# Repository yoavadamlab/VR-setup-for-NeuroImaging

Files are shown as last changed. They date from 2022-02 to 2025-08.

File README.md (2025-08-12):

# Compact virtual realilty setup for neuroimaging

Using this stetup, we study neural activity in the mouse hippocampus during virtual navigation using voltage imaging & calcium imaging, and combining both with optogenetics.

Here we share the hardware &amp; software we developed for the behavioral setup.



## 3D printings
 
 We based our wheel design on [Arthur Sugden](https://github.com/asugden/bebox/tree/master/3d/wheel) model with slight changes.
 
 Our models can be found in [`3D models`](https://github.com/yoavadamlab/VR-setup-for-NeuroImaging/tree/main/3D%20models) directory which contains models for:
 
 - The wheel
 - U shape base for the wheel axis
 - Holders and axle
 - Screen for VR projection

Have a look [here](https://github.com/yoavadamlab/VR-setup-for-NeuroImaging/blob/main/3D%20models/Assembly.STL) on the assembled model.

## Electronics & more

- [Capacitance sensor](https://www.sparkfun.com/products/12041) - for lick detection.
- [Solenoid valve](https://theleedifference.com/products/#solenoid-valves/3) - for reward control.
- [H bridge](https://m.banggood.com/10-Pcs-Geekcreit-L298N-Dual-H-Bridge-Stepper-Motor-Driver-Board-p-1054211.html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) - for switching the 5V coming out of the Arduino with a 12V supply for the valve.
- [Rotary encoder](https://www.ia.omron.com/data_pdf/cat/e6b2-c_ds_e_6_1_csm491.pdf?id=487) - for recording the movement of the wheel.
- [Arduino Uno](https://docs.arduino.cc/hardware/uno-rev3) - controlling the electrical devices and recording inputs.
- [LED projector](https://www.optoma.com/ap/product/ml750st/#) - project the VR environment.
- [500 nm shortpass filter](https://www.edmundoptics.com/p/500nm-50mm-diameter-od-4-shortpass-filter/27788/) - prevent interference of light from the projector into the microscope objective. 
- [Bearings](https://www.4project.co.il/product/flanged-ball-bearing-5x14x5).

### Motorized control setup

We use this setup with mice freely running on the wheel, performing a behavioral task, or for motorized controlled locomotion experiment. Motorzied control uses the following: 

- [Motor](https://www.pololu.com/product/2207)
- [Motor controller](https://www.pololu.com/product/1376)

## Hardware all together

 We based the Wheel on [ThorLabs Breadboard](https://www.thorlabs.com/newgrouppage9.cfm?objectgroup_id=159) with ThorLabs standared posts and connectors.

### Mouse head fixation

 The mice head is fixed using [Neurotar head fixation system](https://www.neurotar.com/the-mobile-homecage/#stability).
 


### Reward delivery and lick detection

A plstic tube (filled with 10% sucrose water for reward delivery), was connected by thin rubber tubes, passing through a solenoid valve, and with the [Neurotar lick port](https://www.neurotar.com/the-mobile-homecage/#stability) at it's end. The solenoid valve was connected to an H-bridge for voltage supply. An electrical wire was soldered to the edge of a needle which compose on the lick port. This wire was connected to a capacitance sensor for mouse lick detection.



We used a motor for motorized control experiments or a rotary encoder for free running experiment:

### Motorized control

The motor was placed on the shaft and controlled by [Pololu control center](https://www.pololu.com/docs/0J44/3.1).



### Rotary encoder

 A rotary encoder was fixed on the shaft of the wheel to track the wheel rotation
  


### Arduino control

The H-bridge, capacitance sensor and the rotary encoder were connected to an Arduino Uno. The Arduino was connected to a standard computer, installed with the ViRMen environment. 



Have a look [here](https://www.circuito.io/app?components=9442,10456,11021,11696,44752,860025) for interactive circutry design.

### The projector

The projector was mounted on the ThorLabs breadboard to project the VR environment on 3D printed screen that was placed in front of the mouse.
 

 
## Software

The VR rendering was designed and executed by [ViRMEn v.2016-02-12](http://pni.princeton.edu/pni-software-tools/virmen-download).
Configurations files for 3 different VR worlds can be found at [`ViRmEn\Mice_Training.mat`](https://github.com/yoavadamlab/VR-setup-for-NeuroImaging/tree/main/ViRmEn).

This is as nexmaple of the virtual environment from the mouse perspective:



Besides the VR design we had to control the following:
- Progress of the virtual environment according to mouse rotation of the wheel
- Delivering specific amounts of reward (sucrose water) at a specified location
- Keep track of the mouse licking (to monitor additional behavior to demonstrate learning of the task)
- Save the behavioral data from the training and imaging sessions for future analysis

The [arduino code](https://github.com/yoavadamlab/VR-setup-for-NeuroImaging/blob/main/Arduino/wheel_control.ino) is used for hardware control. Data is sent to Virmen every 10 ms via serial port communication to indicate whether a lick occured and the amount of wheel rotation.
Virmen also sends data to the arduino via the same serial port, to indicate when to open the valve for reward delivery.
We also supply compiled arduino files for automatic initialization of the arduino board from the virmen script.

The software allows flexible training logic based on the mouse progress. In the beginning of each training session, the trainer needs to declare the current training stage:



Then, the mouse meta-data should be given:



Now, training begins and we can track the mouse preformance:



The virmen experiment and moveforward code can be found at [`ViRmEn`](https://github.com/yoavadamlab/VR-setup-for-NeuroImaging/tree/main/ViRmEn) directory.
After training finished the mouse training data was saved as a csv. file and an automated python script is running to preform analytics of the current training session. The script sends summary data to the lab members emails with the curnet day data, including plots regarding the training history of the mouse:



Have a look at the [daily summary plots](https://github.com/yoavadamlab/VR-setup/files/7994692/daily_plots.2.pdf).

The code for the behavioral analysis can be found in the [`Behavior Analysis`](https://github.com/yoavadamlab/VR-setup-for-NeuroImaging/blob/main/Behavior%20Analysis/Mice_training_data_analysis_wheel_setting.py) directory.

## Contact us

For more information and quetsions you are welcome to contact us by openning an issue.

## Contributors
Project was led by [Yaniv Melamed](https://elsc.huji.ac.il/lab-members/yaniv-melamed/) in collaboration with [Rotem Kipper](https://elsc.huji.ac.il/lab-members/rottem-kipper/) and advice from all [Adam Lab members](https://elsc.huji.ac.il/people-directory/faculty-members/yoav-adam/). 3D priniting was provided by [ELSC FabLab](https://elsc.huji.ac.il/research-and-facilities/expertise-centers/elsc-fablab/).

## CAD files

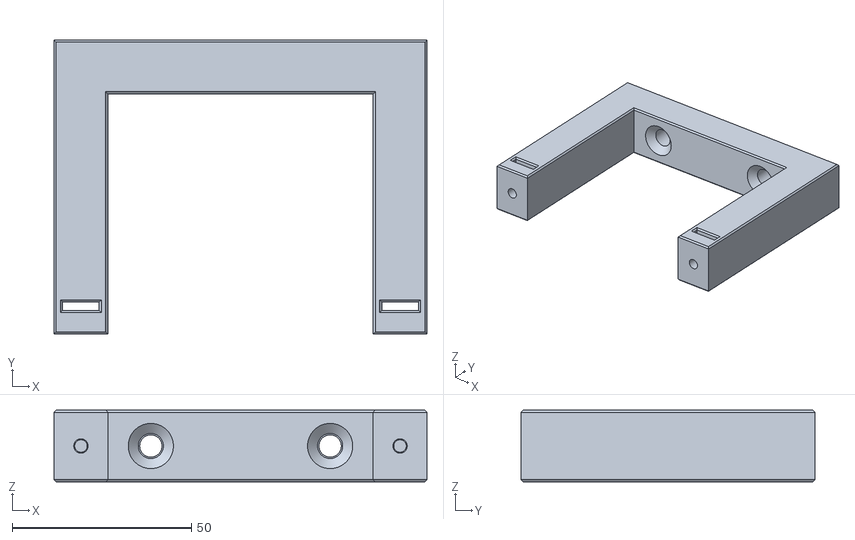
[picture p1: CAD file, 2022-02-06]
3D models/base and axle/Base V4.stl
104.0 x 82.0 x 20.0

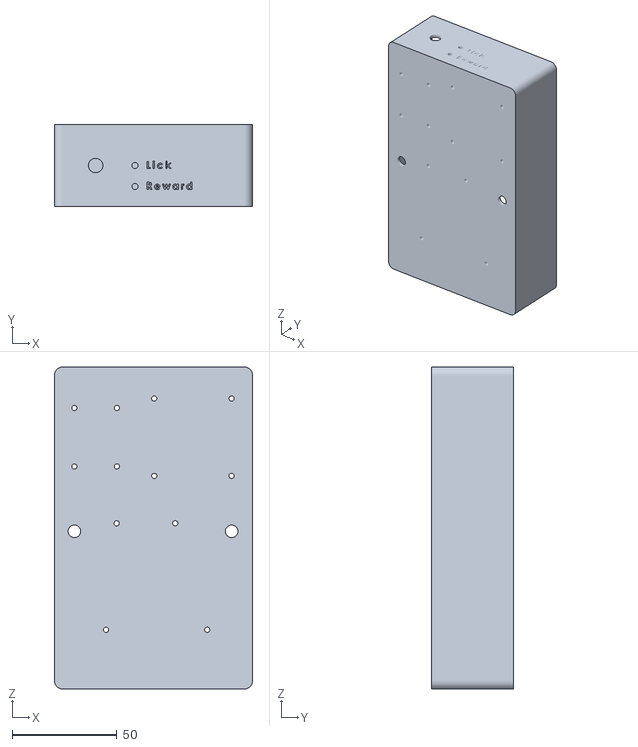
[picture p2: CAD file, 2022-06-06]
3D models/Circuit Box/Github just case.STL
94.6 x 39.0 x 153.6

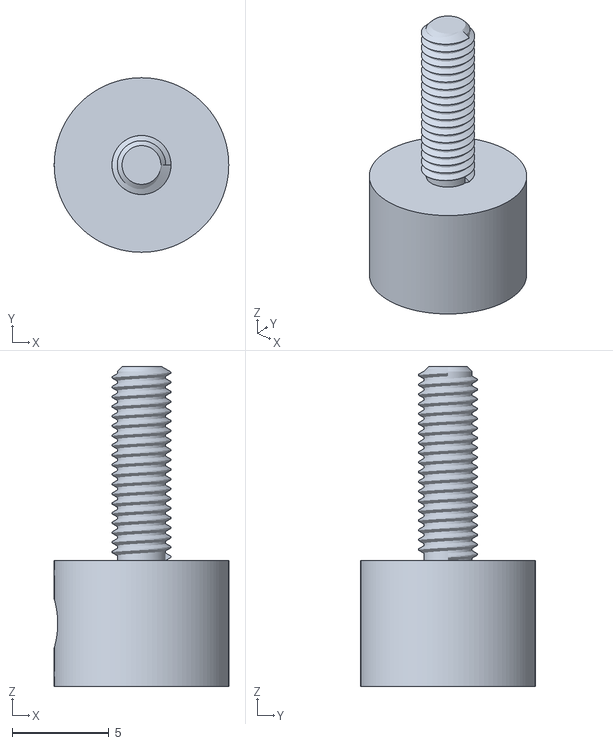
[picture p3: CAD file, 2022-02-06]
3D models/Motor parts/Motor insert V4.stl
9.00 x 9.00 x 16.5

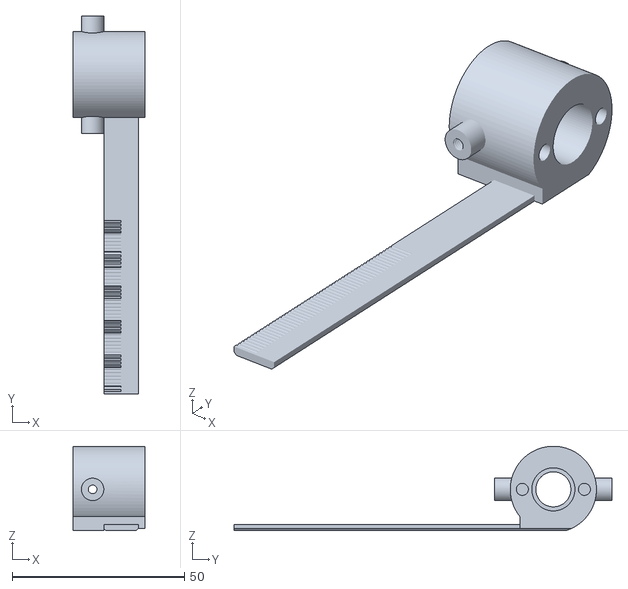
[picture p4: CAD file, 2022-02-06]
3D models/Rotary Encoder parts/Encoder holder V4.stl
21.0 x 109.6 x 24.5

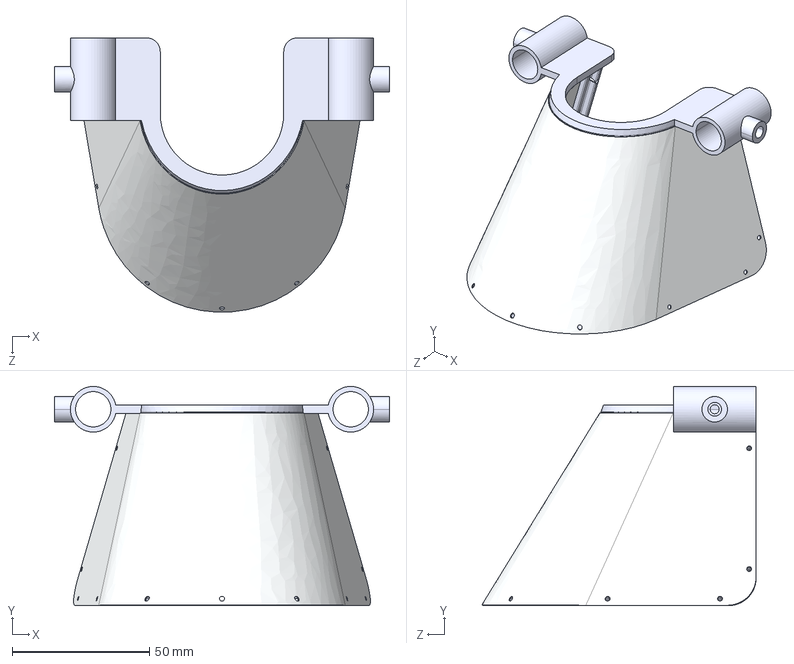
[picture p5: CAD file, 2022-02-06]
3D models/Screen/Tunnel.STEP
122.1 x 79.9 x 100.0 mm

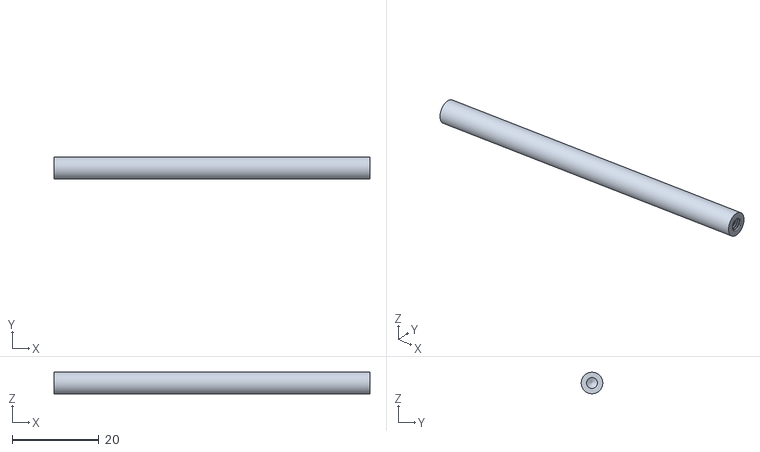
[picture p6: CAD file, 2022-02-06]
3D models/base and axle/Axle.stl
73.0 x 5.00 x 5.00

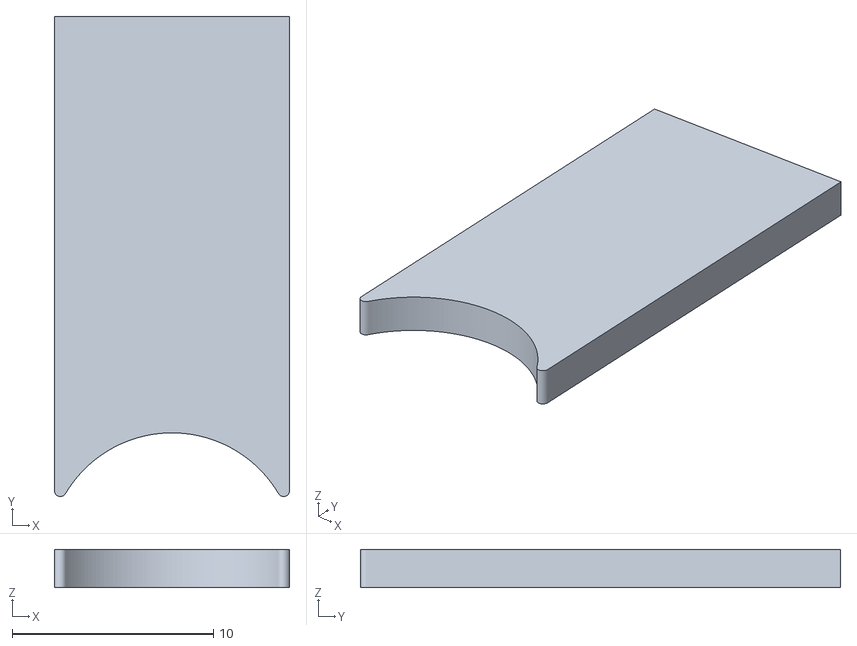
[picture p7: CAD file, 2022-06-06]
3D models/Circuit Box/Github just cable stoppers [print twice].STL
11.7 x 23.9 x 1.90

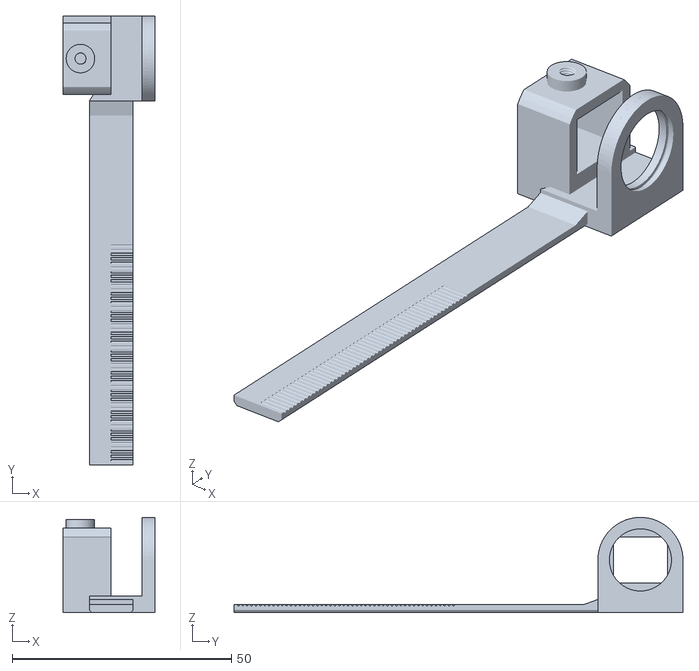
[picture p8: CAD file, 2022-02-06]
3D models/Motor parts/Motor holder V4.stl
21.0 x 102.3 x 21.7

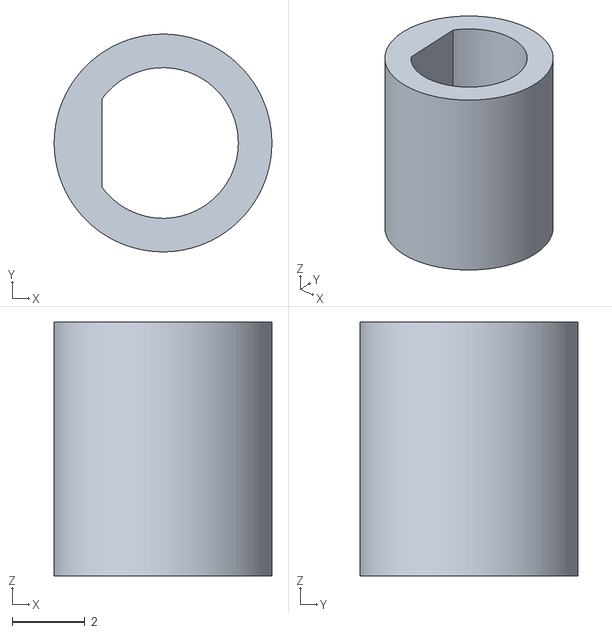
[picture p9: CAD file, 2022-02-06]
3D models/Rotary Encoder parts/Encoder axle adaptor V4.stl
6.00 x 6.00 x 7.00

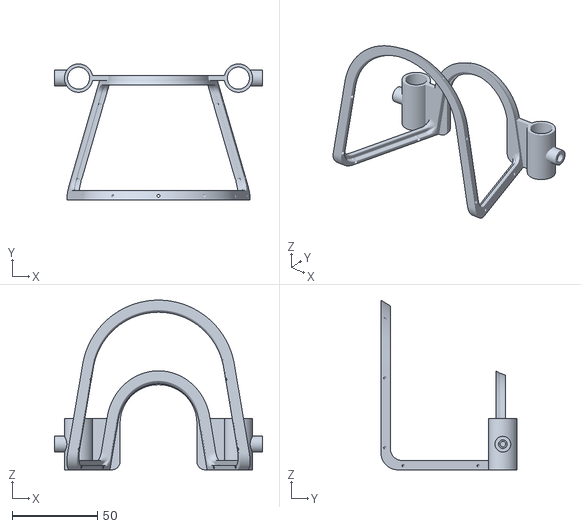
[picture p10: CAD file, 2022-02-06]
3D models/Screen/Tunnel structure.STL
122.1 x 79.9 x 99.7

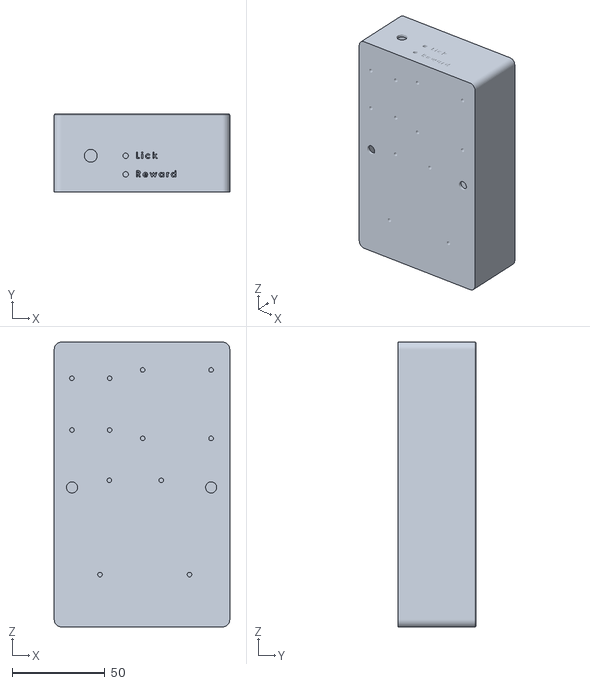
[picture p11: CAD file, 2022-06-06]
3D models/Circuit Box/Base.STL
94.6 x 42.0 x 153.6

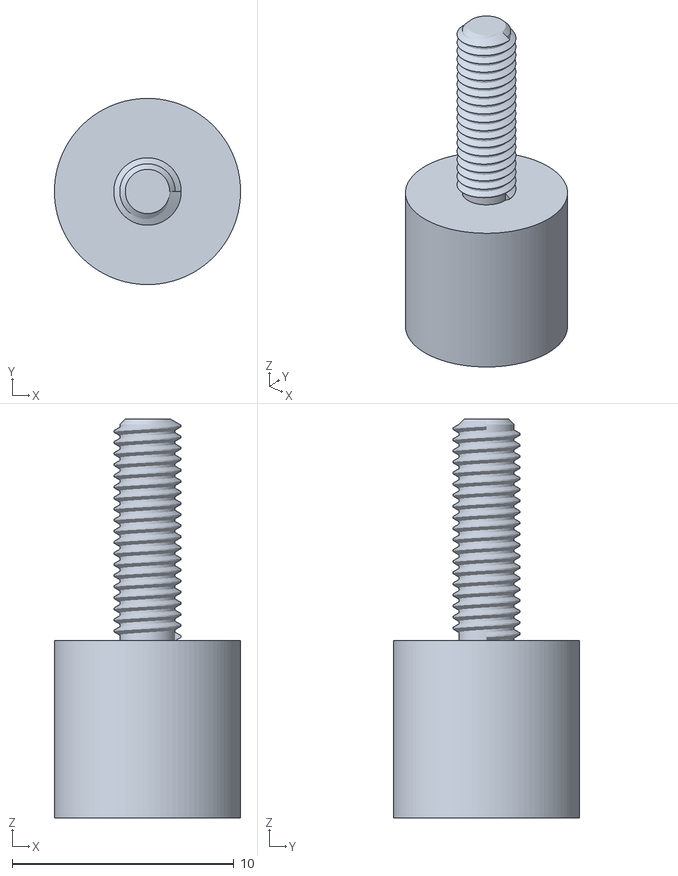
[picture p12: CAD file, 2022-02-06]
3D models/Rotary Encoder parts/Encoder insert V4.stl
8.40 x 8.40 x 18.0

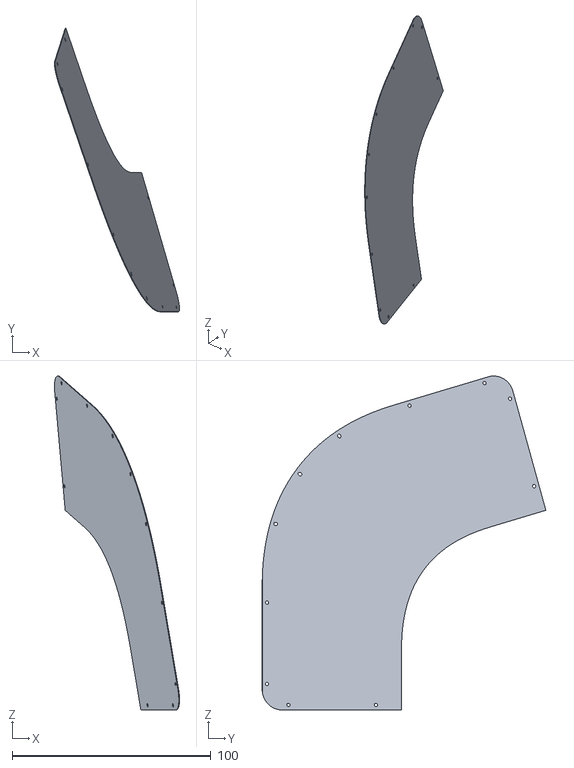
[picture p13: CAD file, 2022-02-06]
3D models/Screen/Tunnel sheet.STL
63.0 x 142.9 x 168.2

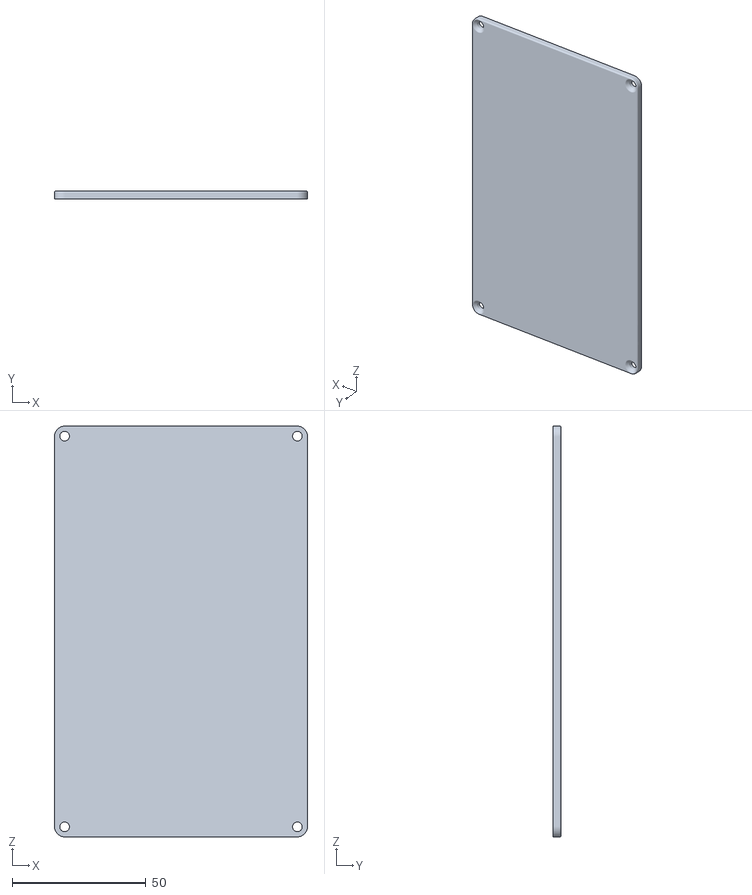
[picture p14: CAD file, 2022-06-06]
3D models/Circuit Box/Github just cover.STL
94.6 x 3.00 x 153.6

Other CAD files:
3D models/Screen/Tunnel.STL

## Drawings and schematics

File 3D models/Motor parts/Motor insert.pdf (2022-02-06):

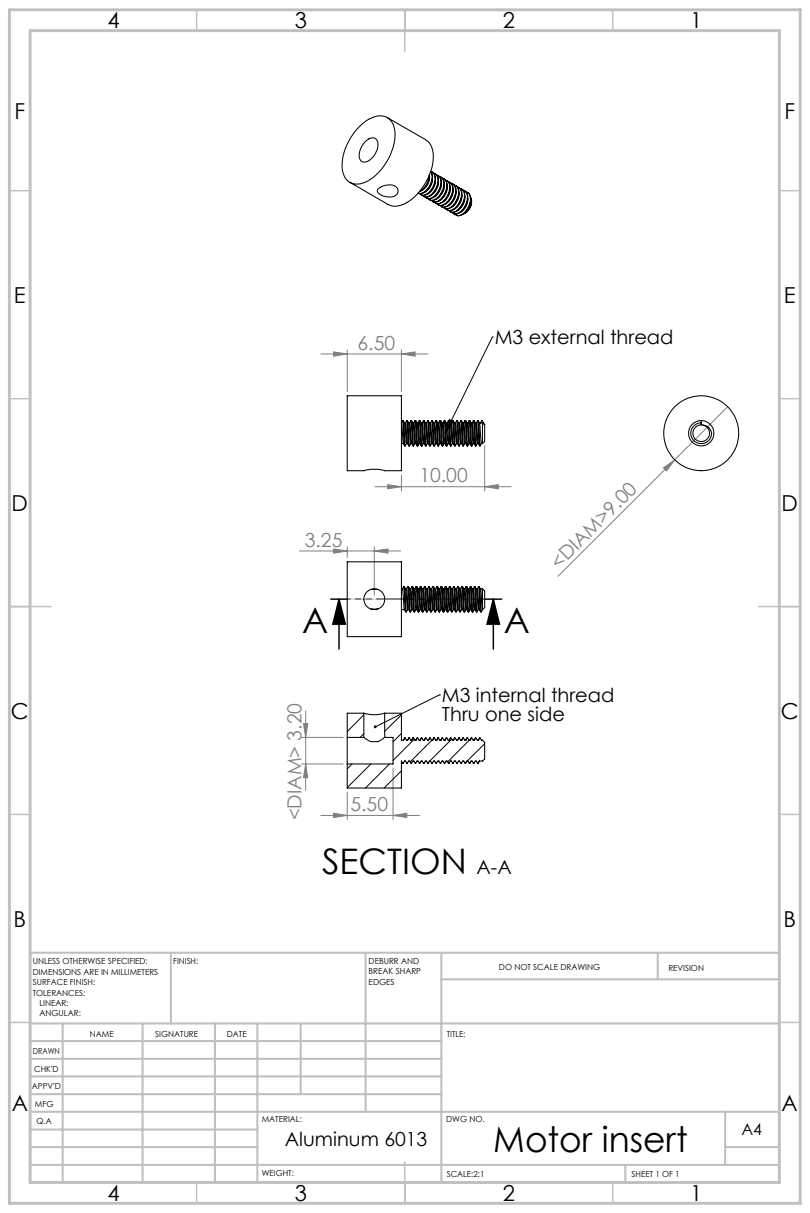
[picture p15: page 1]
M3 external thread; <DIAM> 3.20; SECTION A-A; FINISH:; DEBURR AND; BREAK SHARP; DO NOT SCALE DRAWING; REVISION; SCALE:2:1; SHEET 1 OF 1

M3 internal thread
Thru one side

UNLESS OTHERWISE SPECIFIED:
DIMENSIONS ARE IN MILLIMETERS
SURFACE FINISH:
TOLERANCES:
LINEAR:
ANGULAR:

NAME | SIGNATURE | DATE | | | | TITLE:

DRAWN
CHK'D
APPV'D
MFG
Q.A | | | | MATERIAL: Aluminum 6013 | DWG NO. Motor insert | A4

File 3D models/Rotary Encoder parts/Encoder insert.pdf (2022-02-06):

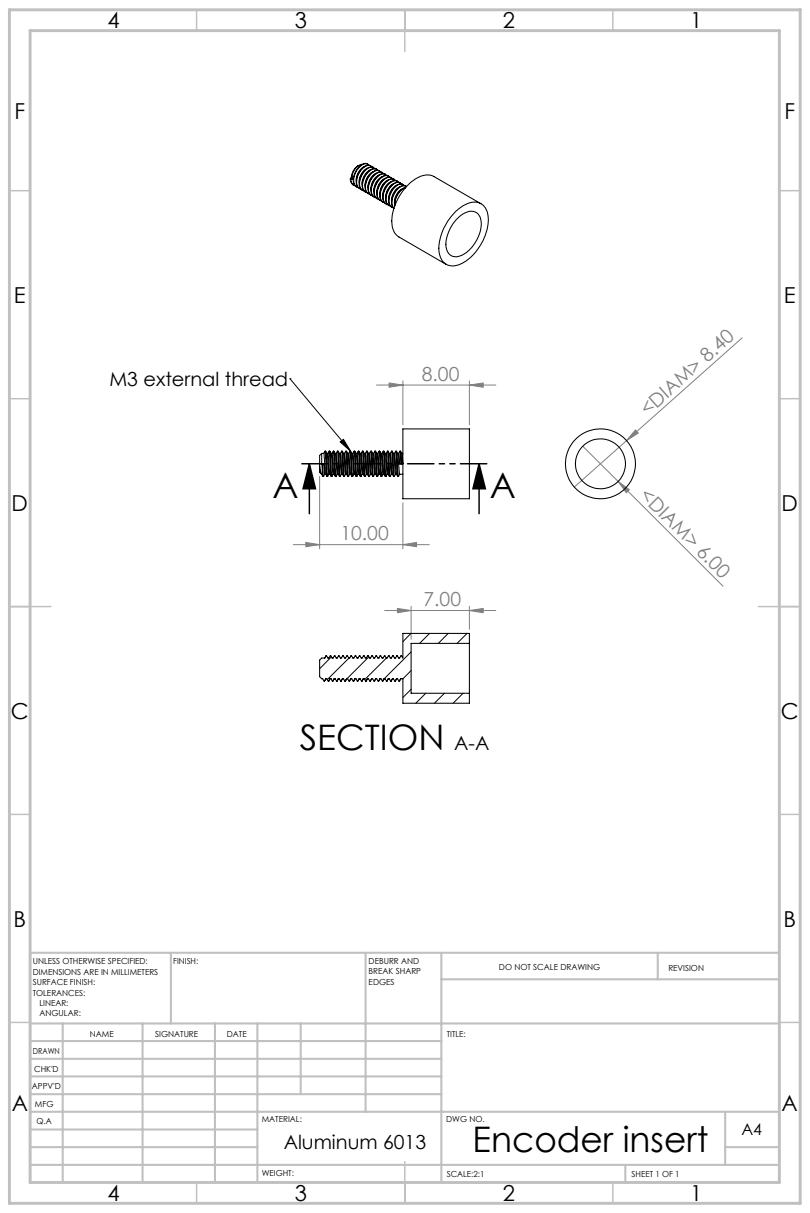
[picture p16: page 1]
M3 external thread; <DIAM> 8.40; <DIAM> 6.00; SECTION A-A; FINISH:; DEBURR AND; BREAK SHARP; DO NOT SCALE DRAWING; REVISION; SCALE:2:1; SHEET 1 OF 1

UNLESS OTHERWISE SPECIFIED:
DIMENSIONS ARE IN MILLIMETERS
SURFACE FINISH:
TOLERANCES:
LINEAR:
ANGULAR:

NAME | SIGNATURE | DATE | | | | TITLE:

DRAWN
CHK'D
APPV'D
MFG
Q.A | | | | MATERIAL: Aluminum 6013 | DWG NO. Encoder insert | A4

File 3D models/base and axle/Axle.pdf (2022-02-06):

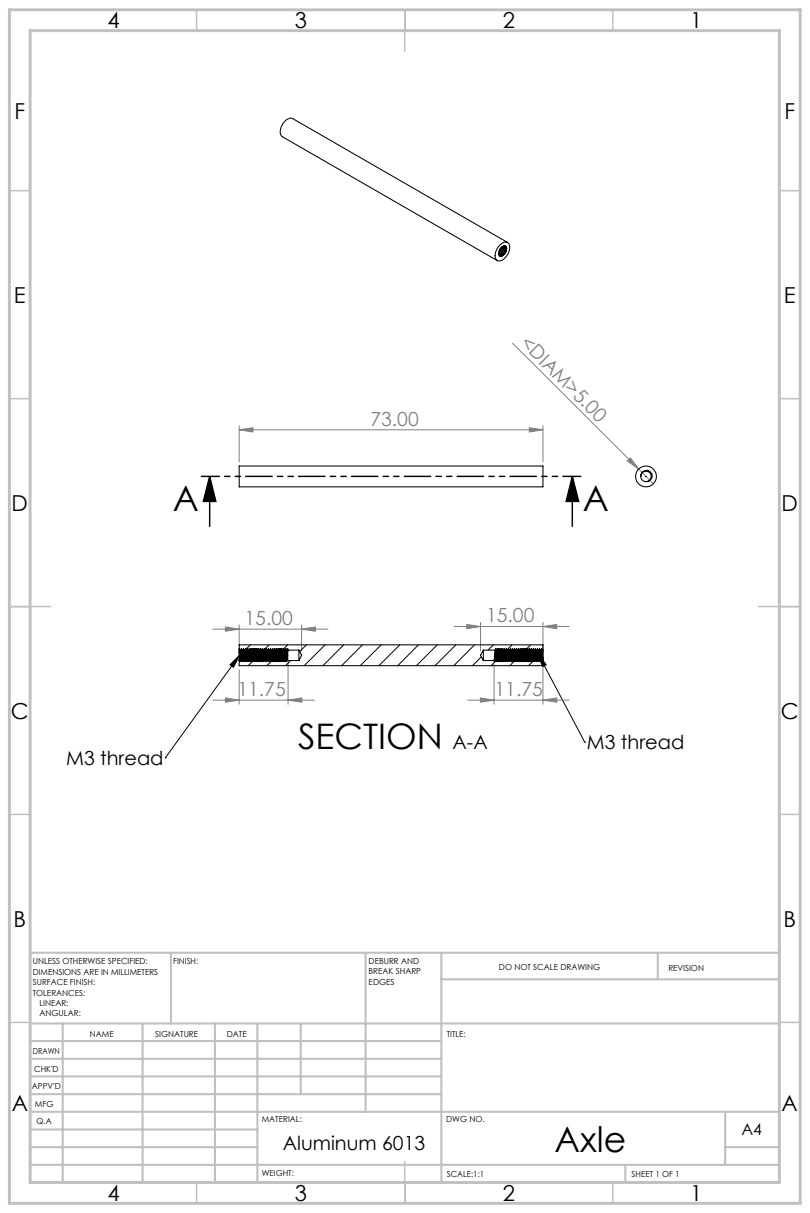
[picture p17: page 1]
SECTION A-A; M3 thread; FINISH:; DEBURR AND; BREAK SHARP; DO NOT SCALE DRAWING; REVISION; SCALE:1:1; SHEET 1 OF 1

UNLESS OTHERWISE SPECIFIED:
DIMENSIONS ARE IN MILLIMETERS
SURFACE FINISH:
TOLERANCES:
LINEAR:
ANGULAR:

NAME | SIGNATURE | DATE | | | | TITLE:

DRAWN
CHK'D
APPV'D
MFG
Q.A | | | | MATERIAL: Aluminum 6013 | DWG NO. Axle | A4

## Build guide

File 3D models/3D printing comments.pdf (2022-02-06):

3D printing comments

1. Wheel holder (All parts)- 3D printed with Prusa MK3s (FDM printer), material PLA+, layer

height 0.2 mm.

2. Wheel - 3D printed with Prusa MK3s, material PLA+, layer height 0.2 mm. Printing slower

than default recommended.

3. Axle- Built by 3 parts. Screw gently but tight each part after inserting the axle into the

wheel and both bearings. The file named "Encoder axle adaptor" should be glued with

super glue into the encoder insert.

4. Encoder installation- screw all the way 2 cupless m3 screw into the encoder. Insert the

encoder all the way into his holder (Make sure that the axle D shape angle is

inserted correctly into the adaptor). Tighten with 8 mm m3 screws from both sides while

pushing the encoder in.

5. Screws needed- Two cupless M3 20 mm screws and 8 mm M3 hex screws (For the

encoder). Cupless 6 mm M3 screw and 8 mm M3 hex screw (For the motor). Two M3 10

mm screws and two M3 brass plastic inserts (For base). Two M4 10 mm hex screws and

two M4 nuts to fix the axle to the wheel

Screen:

6. Sturcture- 3D printed with SLA printer, facing the screen up. It is also possible to print the

same orientation on an FDM printer with 100% infill, but the result might be fragile.

7. Screen- 3D printed with FDM printer, material white PLA+ , layer height 0.1 m"m. Ironing

feature recommended.

8. Assembly- M2 screws to assemble the sheet with the structure (Tapping ahead

recommended). M6 screws for the fixture of the structure to the set

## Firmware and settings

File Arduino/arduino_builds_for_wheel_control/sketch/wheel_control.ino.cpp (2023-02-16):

#include <Arduino.h>
#line 1 "C:\\Users\\Adam Lab\\Desktop\\wheel_control_WITH_VIRMEN_TO_ts_OUTPUT\\wheel_control\\wheel_control.ino"
// pin numbers
int reward_pin = 5; // pin connected to the reward valve
int lick_pin = 4;
int trigger_pin = 6; // imaging trigger from ThorImage DAQ
// signals values from virmen
int virmen_signal = 0; // signal from virmen, initialize to 0. 0 mean that no signal was send
int REWARD_SIGNAL = 1; // signal from virmen that a new session started
int START_SIGNAL = 2; // signal from virmen that a new session started
int END_SIGNAL = 3; // signal from virmen that a new session started
// variables
int last_lick_state = 0;
int lick_counter = 0;   
int reward_duration = 40;
int imaging_trigger = 0;
unsigned long last_send = 0;
int send_interval = 10; // send data to virmen each 10 ms
bool finish_session = false ;
// variables for movement detection
int encoder_A = 2; //connected to digital 2, black
int encoder_B = 3; //connected to digital 3, white
volatile long last_counter, movement_counter = 0; //This variable will increase or decrease depending on the rotation of encoder
const int p_revolutions = 400; // number of pulses per revolution
 // variables for ThosSync TTL (which needed to validate merging Imaging and Behavior)
int ttl_duration = 10;
int TTL_SIGNAL = 4; // signal from virmen that a record just saved to csv
int reward_ttl_pin = 7;
int LAP_END_SIGNAL = 5;
// variables for lick ttl
bool lick_report_to_TS = false;
int lick_ttl_pin = 8;
unsigned long lick_report_start_time = 0;
int lick_ttl_duration = 10;

#line 34 "C:\\Users\\Adam Lab\\Desktop\\wheel_control_WITH_VIRMEN_TO_ts_OUTPUT\\wheel_control\\wheel_control.ino"
void setup();
#line 51 "C:\\Users\\Adam Lab\\Desktop\\wheel_control_WITH_VIRMEN_TO_ts_OUTPUT\\wheel_control\\wheel_control.ino"
void loop();
#line 62 "C:\\Users\\Adam Lab\\Desktop\\wheel_control_WITH_VIRMEN_TO_ts_OUTPUT\\wheel_control\\wheel_control.ino"
int read_virmen_signal();
#line 71 "C:\\Users\\Adam Lab\\Desktop\\wheel_control_WITH_VIRMEN_TO_ts_OUTPUT\\wheel_control\\wheel_control.ino"
void start_session();
#line 80 "C:\\Users\\Adam Lab\\Desktop\\wheel_control_WITH_VIRMEN_TO_ts_OUTPUT\\wheel_control\\wheel_control.ino"
void end_session();
#line 87 "C:\\Users\\Adam Lab\\Desktop\\wheel_control_WITH_VIRMEN_TO_ts_OUTPUT\\wheel_control\\wheel_control.ino"
void lick_control();
#line 102 "C:\\Users\\Adam Lab\\Desktop\\wheel_control_WITH_VIRMEN_TO_ts_OUTPUT\\wheel_control\\wheel_control.ino"
void send_lick_ttl_to_TS();
#line 110 "C:\\Users\\Adam Lab\\Desktop\\wheel_control_WITH_VIRMEN_TO_ts_OUTPUT\\wheel_control\\wheel_control.ino"
void reward_control();
#line 123 "C:\\Users\\Adam Lab\\Desktop\\wheel_control_WITH_VIRMEN_TO_ts_OUTPUT\\wheel_control\\wheel_control.ino"
void send_data_to_virmen();
#line 143 "C:\\Users\\Adam Lab\\Desktop\\wheel_control_WITH_VIRMEN_TO_ts_OUTPUT\\wheel_control\\wheel_control.ino"
void a_rise();
#line 154 "C:\\Users\\Adam Lab\\Desktop\\wheel_control_WITH_VIRMEN_TO_ts_OUTPUT\\wheel_control\\wheel_control.ino"
void b_rise();
#line 163 "C:\\Users\\Adam Lab\\Desktop\\wheel_control_WITH_VIRMEN_TO_ts_OUTPUT\\wheel_control\\wheel_control.ino"
void check_if_end_revolution();
#line 34 "C:\\Users\\Adam Lab\\Desktop\\wheel_control_WITH_VIRMEN_TO_ts_OUTPUT\\wheel_control\\wheel_control.ino"
void setup() {
  pinMode(trigger_pin, INPUT);
  pinMode(reward_pin, OUTPUT);
  pinMode(lick_pin, INPUT);
  pinMode(reward_ttl_pin, OUTPUT);
  pinMode(lick_ttl_pin, OUTPUT);
  // interupt pins
  pinMode(encoder_A, INPUT_PULLUP); // internal pullup input pin 2
  pinMode(encoder_B, INPUT_PULLUP); // internal pullup input pin 3
  attachInterrupt(digitalPinToInterrupt(encoder_A), a_rise, RISING); //A rising pulse from encodenren activated ai0()
  attachInterrupt(digitalPinToInterrupt(encoder_B), b_rise, RISING); //B rising pulse from encodenren activated ai1()
  Serial.begin(38400);
  while (!Serial) delay(1);
  //while (Serial.available()) Serial.read(); // this line is for flushing the serial. we didn't need it, but keep it here just in case 
}


void loop() {
  virmen_signal = read_virmen_signal();
  start_session();
  //end_session();
  imaging_trigger = digitalRead(trigger_pin);
  reward_control();
  lick_control();
  send_data_to_virmen();
  //send_TTL_to_TS();
}

int read_virmen_signal() {
  int val = 0; // if nothing was send from virmen set to 0
  if (Serial.available() > 0)  // if data in the reader buffer
  {
     val = Serial.read();
    }
  return val;
}

void start_session() {
   if (virmen_signal == START_SIGNAL)
    {
    lick_counter = 0;
    movement_counter = 0;
    finish_session = false;
    }
}

void end_session() {
   if (virmen_signal == END_SIGNAL)
    {
    finish_session = true;
    }
}

void lick_control(){
  int lick = digitalRead(lick_pin);
  if (last_lick_state != lick)
  {
    lick_counter += lick;
    send_lick_ttl_to_TS();
  }
  last_lick_state = lick;
  if ((lick_report_to_TS == true) && ((millis() - lick_report_start_time) >= lick_ttl_duration))
  {
    digitalWrite(lick_ttl_pin, LOW);
    lick_report_to_TS = false;
  }
  }

void send_lick_ttl_to_TS(){
  if ((lick_report_to_TS == false) && (last_lick_state ==0))
  {  
    digitalWrite(lick_ttl_pin, HIGH);
    lick_report_to_TS = true;
    lick_report_start_time = millis();
  }
}
void reward_control() {
   if (virmen_signal == REWARD_SIGNAL)
      {
      digitalWrite(reward_pin, HIGH);
      digitalWrite(reward_ttl_pin, HIGH);
      unsigned long start = millis();
      while ((millis() - start) < reward_duration)  {  
        }   
      digitalWrite(reward_pin, LOW); 
      digitalWrite(reward_ttl_pin, LOW);  
        }
}
 
void send_data_to_virmen() {
  unsigned long t = millis();
  if ((t - last_send) > send_interval) 
  {
    last_send = t;
    Serial.print("_");
    Serial.print(movement_counter);
    Serial.print("_");
    Serial.print(lick_counter);
    Serial.print("_");
    Serial.print(imaging_trigger);
    Serial.println("_");
   }
  
}

// movement methods

  // activated if encoder_A is going from LOW to HIGH
  // Check encoder_B to determine the direction
  void a_rise() 
  {
  if(digitalRead(encoder_B)==LOW) 
    { movement_counter++;}
  else 
    { movement_counter--;}
  check_if_end_revolution();
  }

  //  activated if encoder_B is going from LOW to HIGH
  // Check encoder_A to determine the direction
  void b_rise() 
  {
  if(digitalRead(encoder_A)==LOW) 
    { movement_counter--;}
  else 
    { movement_counter++;}
  check_if_end_revolution();
  }

  void check_if_end_revolution()
  {
    if (movement_counter == p_revolutions)
    {movement_counter = 0;}
  }

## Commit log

2022-01-30 upload code and README darft
    [15.12.21.csv, OP10.csv, training_metadata_from_virmen.csv]
2022-02-06 3d models
    [Axle V4.stl, Base V4.stl, Encoder axle adaptor V4.stl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]
2022-06-06 Create Circuit Box
2022-06-06 Update wheel code
2023-02-16 upgrade virmen and arduino code for TS
2023-02-16 add compiled arduino files
